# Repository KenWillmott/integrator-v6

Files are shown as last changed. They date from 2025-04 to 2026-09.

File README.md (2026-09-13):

# integrator-v6
guitar pickup test integrator V6.x

This hardware version of the integrator replaces the much older V5.8/V5.9 integrator.
General information about the integrator project is found here, along with the older design files:

https://github.com/KenWillmott/integrator/wiki

The newer V6.0 is a smaller, more integrated version of the same circuit, with upgraded components. It is possible to order a build from the factory. The BOM is a complete build, with all components, including switches and connectors. It is a fully functional integrator, needs only to be calibrated to work. A case or enclosure is recommended, So far an aluminum and an acrylic case have been used. It is possible to special order the boards without switches and connectors by noting them DNP on a modified BOM.

Complete BOM: [BOM-V601(2025-04-11).xls](https://github.com/KenWillmott/integrator-v6/blob/main/BOM-V601(2025-04-11).xls)

The project is listed at the PCBWay site, you can place an multi-board order there by following the ordering links and specifying "PCB+Assembly".
[PCBWay order link](https://www.pcbway.com/project/shareproject/W22492BSH46_integrator_V6_Gerber_e358a0f5.html)

Note that you can produce the PCB by any method, by importing the KiCad project and exporting the necessary fabrication files.

## Important!:
Some manufacturers and myself, have had problems sourcing the 3-way switch. So I provided onboard solder jumper J1 to select between 3-way (100-SP3) and 2-way
(100-SP1) switches. If the 100-SP3 is available, PCB V6.02 will work with no modifications and PCB 6.03 requires a solder blob on J1. If the 100-SP1 must be used, PCB V6.03 will work with no modifications and PCB V6.02 requires that C1 be either removed or not placed during production. Using the ON-ON functioning of the 100-SP1 will sacrifice the ability to make approximate inductance measurements, while preserving the no-load and loaded settings (which are the most important ones).

board-J1-settings

From a pure manufacturing point of view, the combinations

V6.02 --> 100SP3T1B4M7QE

V6.03 --> 100SP1T1B4M7QE

are preferred, since those configurations require no board or BOM modifications. However, V6.02 may be deprecated soon, since it's easier to modify V6.03 for either switch type.

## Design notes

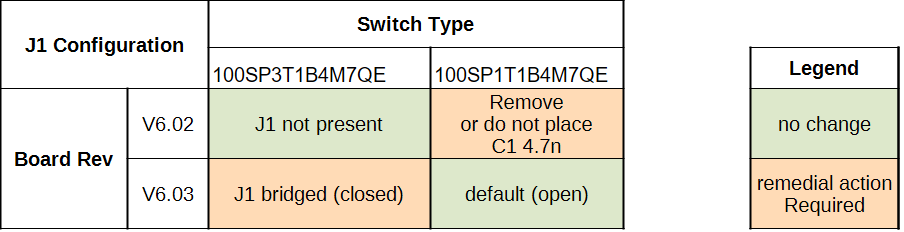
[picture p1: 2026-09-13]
board-J1-settings.png

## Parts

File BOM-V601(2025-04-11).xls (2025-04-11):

 |  |  | V6.02 Integrator BOM 2015-04-11
Item # | *Designator | *Qty | Manufacturer | *Mfg Part # | Description / Value | *Package/Footprint | Mounting Type
1 | R9,R6 | 2 | Yageo | RC0603JR-071M8L | 1.8M | R_0603_1608Metric | SMD
2 | C9,C12,C11 | 3 | Kemet | C0805C106K4PACTU | 10u 16V | C_0805_2012Metric | SMD
3 | R11,R12 | 2 | Yageo | RC0603FR-071KL | 1.0k | R_0603_1608Metric | SMD
4 | R5 | 1 | Yageo | RC0603JR-0718KL | 18k | R_0603_1608Metric | SMD
5 | J1 | 1 | TE Connectivity | 284391-3 | Screw_Terminal_01x03 | TerminalBlock_4Ucon_1x03_P3.50mm_Vertical | thru-hole
6 | R10,R7,R8 | 3 | Yageo | RC0603FR-1339KL | 39k | R_0603_1608Metric | SMD
7 | D1 | 1 |  | LTST-C191KRKT | LED | LED_0603_1608Metric | SMD
8 | U1 | 1 | Texas Instruments | TL084HIDR | Quad Op Amp | SOIC-14_3.9x8.7mm_P1.27mm | SMD
9 | J3 | 1 | CUI | SJ1-3525N | AudioJack2_Ground_Switch | Jack_3.5mm_CUI_SJ1-3525N_Horizontal | thru-hole
10 | C2 | 1 | Kemet | C0603X471K4RACAUTO | 470p | C_0603_1608Metric | SMD
11 | C7,C6 | 2 | Kemet | C0603C104K4RACTU | 100n | C_0603_1608Metric | SMD
12 | R4 | 1 | Yageo | RC0603FR-0710KL | 10k | R_0603_1608Metric | SMD
13 | D2 | 1 | EVVO | 1N4001W | 1N4001 | D_SOD-123 | SMD
14 | R1 | 1 | Yageo | RC0603FR-079M1L | 9.1M | R_0603_1608Metric | SMD
15 | C5 | 1 | EW Electronics | GKG30086 | 30p | C_Trimmer | SMD
16 | R2 | 1 | Yageo | RC0603JR-07200KL | 200k | R_0603_1608Metric | SMD
17 | C4 | 1 | Kemet | C0603C180J4GACTU | 18p | C_0603_1608Metric | SMD
18 | C8 | 1 | Kemet | C0603C105K4RACTU | 1.0u | C_0603_1608Metric | SMD
19 | SW1 | 1 | E-Switch | 100SP3T1B4M7QE | SW_SPDT_MSM | SPDT Toggle Switch | thru-hole
20 | R3 | 1 | Yageo | RC0603FR-071ML | 1.0M | R_0603_1608Metric | SMD
21 | U2 | 1 | ST Micro | L78L06ABUTR | L78L06_SOT89 | SOT-89-3 | SMD
22 | J2 | 1 | Tensility International | 54-00131 | Barrel_Jack_Switch | BarrelJack_GCT_DCJ200-10-A_Horizontal | thru-hole
23 | C3 | 1 | Kemet | C0603C399D4HACTU | 3.9p | C_0603_1608Metric | SMD
24 | C10 | 1 | Kemet | C0603C103M4RACTU | 10n | C_0603_1608Metric | SMD
25 | C1 | 1 | Kemet | C0603C472K4RACTU | 4.7n | C_0603_1608Metric | SMD

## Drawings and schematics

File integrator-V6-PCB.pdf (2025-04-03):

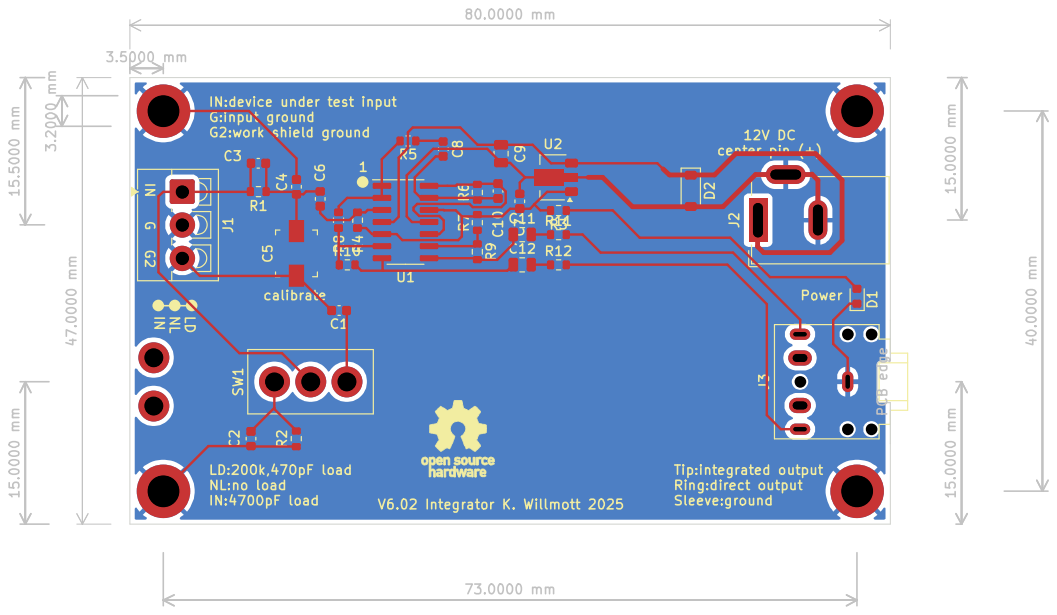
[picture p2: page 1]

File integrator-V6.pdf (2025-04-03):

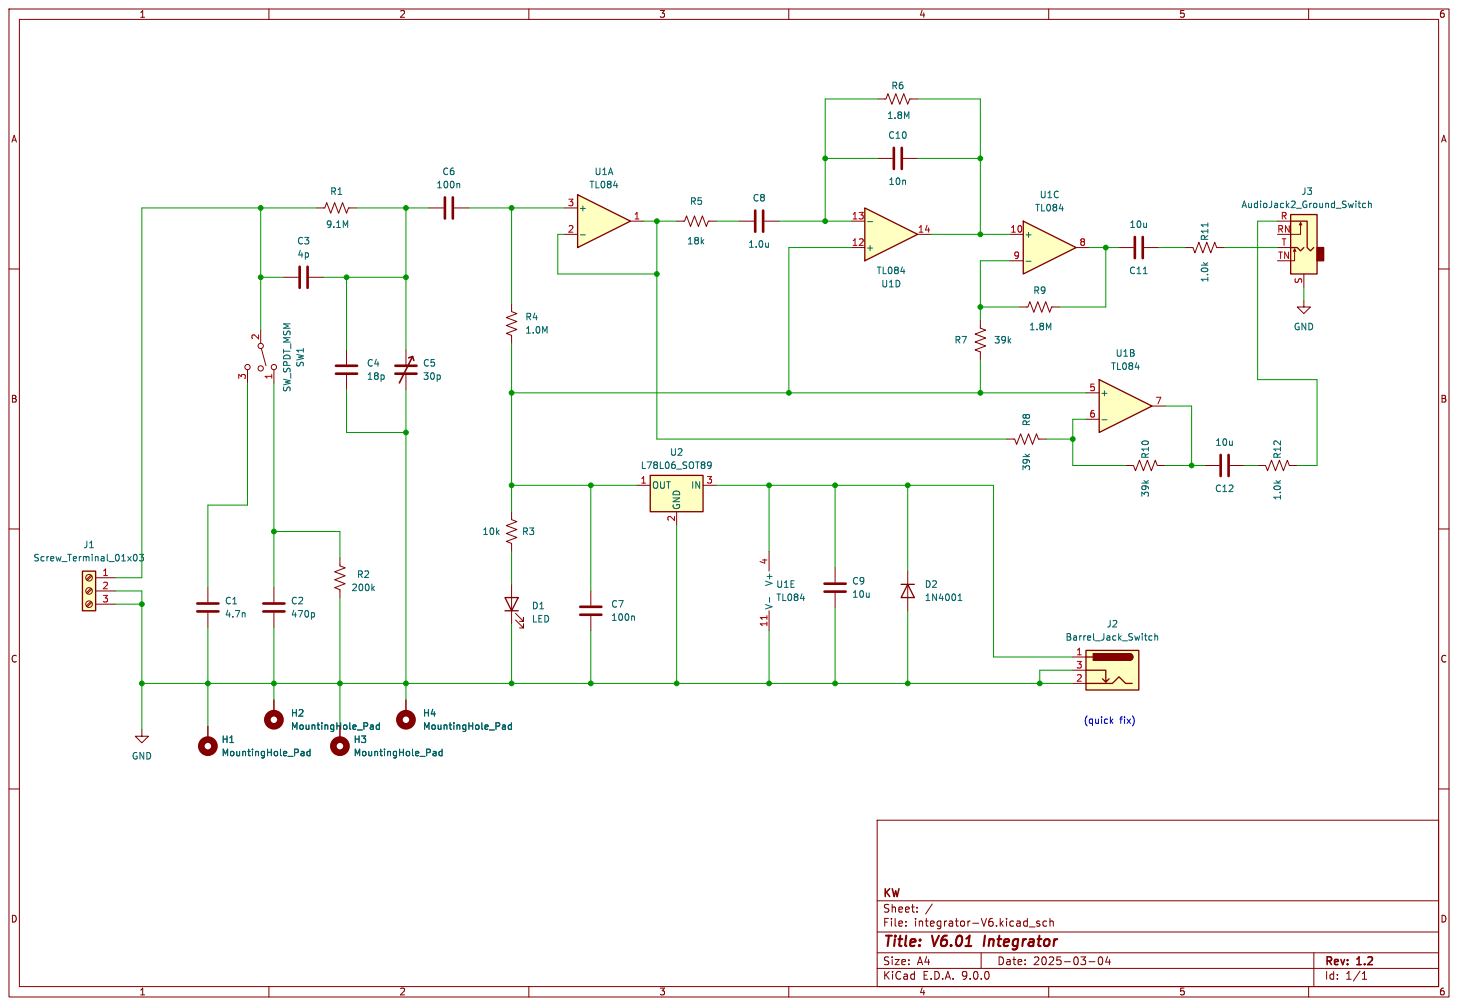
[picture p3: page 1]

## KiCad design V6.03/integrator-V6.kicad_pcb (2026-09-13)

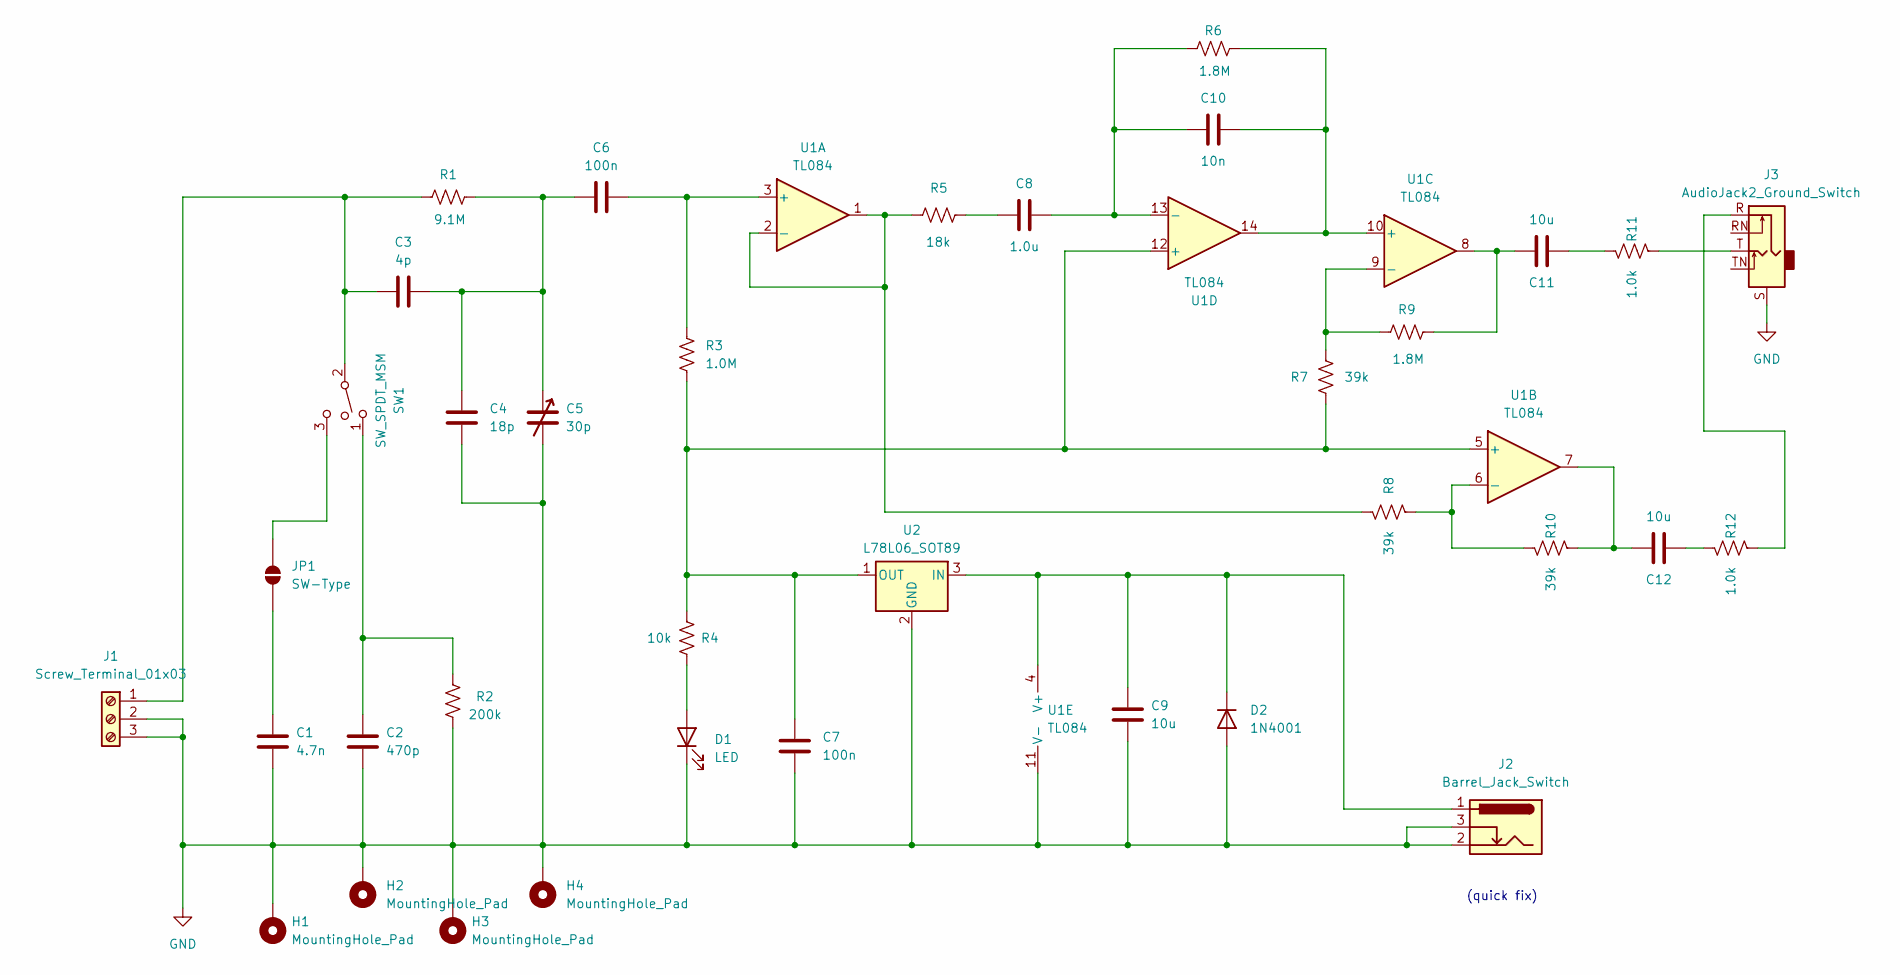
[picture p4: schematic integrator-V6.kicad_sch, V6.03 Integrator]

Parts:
C1: 4.7n; C_0603_1608Metric
C2: 470p; C_0603_1608Metric
C3: 4p; C_0603_1608Metric
C4: 18p; C_0603_1608Metric
C5: 30p; C_Trimmer_Murata_TZB4-A
C6, C7: 100n; C_0603_1608Metric
C8: 1.0u; C_0603_1608Metric
C9, C11, C12: 10u; C_0805_2012Metric
C10: 10n; C_0603_1608Metric
D1: LED; LED_0603_1608Metric
D2: 1N4001; D_SOD-123
H1, H2, H3, H4: MountingHole_Pad; MountingHole_3.2mm_M3_DIN965_Pad
J1: Screw_Terminal_01x03; TerminalBlock_4Ucon_1x03_P3.50mm_Vertical
J2: Barrel_Jack_Switch; BarrelJack_GCT_DCJ200-10-A_Horizontal
J3: AudioJack2_Ground_Switch; Jack_3.5mm_CUI_SJ1-3525N_Horizontal
JP1: SW-Type; SolderJumper-2_P1.3mm_Open_RoundedPad1.0x1.5mm
R1: 9.1M; R_0603_1608Metric
R2: 200k; R_0603_1608Metric
R3: 1.0M; R_0603_1608Metric
R4: 10k; R_0603_1608Metric
R5: 18k; R_0603_1608Metric
R6, R9: 1.8M; R_0603_1608Metric
R7, R8, R10: 39k; R_0603_1608Metric
R11, R12: 1.0k; R_0603_1608Metric
SW1: SW_SPDT_MSM; MTS-103 Switch
U1: TL084; SOIC-14_3.9x8.7mm_P1.27mm
U2: L78L06_SOT89; SOT-89-3

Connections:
GND: C1.2, C2.2, C4.1, C5.2, C7.2, C9.2, D1.1 (K), D2.2 (A), H1.1 (1_1), H2.1 (1_1), H3.1 (1_1), H4.1 (1_1), J1.2, J1.3, J2.2, J2.3, J3.S, R2.1, U1.11 (V-), U2.2 (GND)
unnamed: C2.1, R2.2, SW1.1
unnamed: C3.2, C4.2, C5.1, C6.2, R1.2
unnamed: C8.2, R5.1
unnamed: C11.1, R9.2, U1.8
unnamed: C11.2, R11.1
unnamed: C12.1, R10.2, U1.7
unnamed: C12.2, R12.1
unnamed: D1.2 (A), R4.2
unnamed: C9.1, D2.1 (K), J2.1, U1.4 (V+), U2.3 (IN)
unnamed: C3.1, J1.1, R1.1, SW1.2
unnamed: J3.R, R12.2
unnamed: J3.T, R11.2
unnamed: C1.1, JP1.1 (A)
unnamed: JP1.2 (B), SW1.3
unnamed: C6.1, R3.1, U1.3 (+)
unnamed: R5.2, R8.1, U1.1, U1.2 (-)
unnamed: C7.1, R3.2, R4.1, R7.2, U1.5 (+), U1.12 (+), U2.1 (OUT)
unnamed: R8.2, R10.1, U1.6 (-)
unnamed: C10.1, R6.2, U1.10 (+), U1.14
unnamed: R7.1, R9.1, U1.9 (-)
unnamed: C8.1, C10.2, R6.1, U1.13 (-)

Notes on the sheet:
(quick fix)

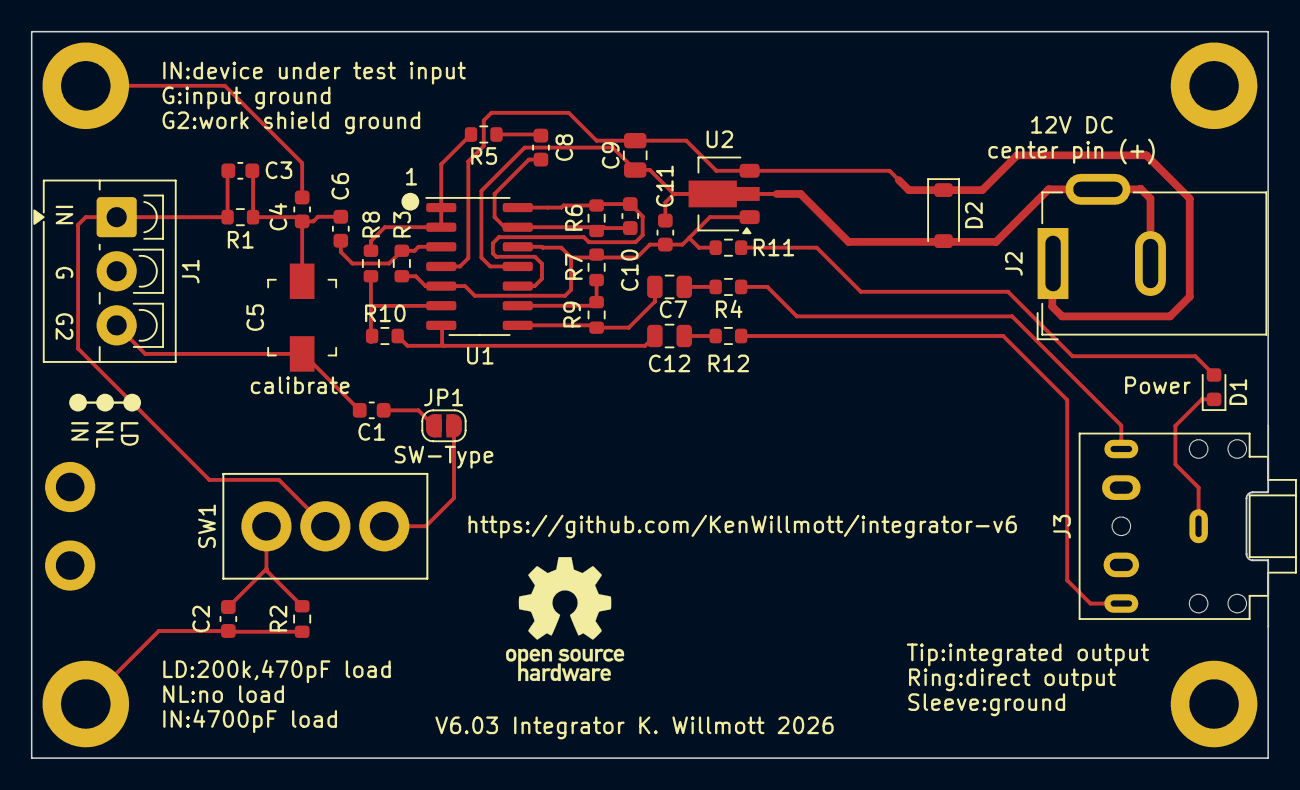
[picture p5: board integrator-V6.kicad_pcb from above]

Board: 2 copper layers, 80.0 x 47.0 mm, 37 parts (0 on the bottom side), 22 nets.

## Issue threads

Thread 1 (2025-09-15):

Sorry not an issue

SoLongSidekick, 2025-09-15:
I'm sorry for using this, Github really needs to add a "comments" section. But if you're open to help with this I'd love to help. I have FDM and resin 3D printers, 40w laser, 2 small CNC machines, uV printer, and have developed a CNC workflow to make PCBs that look like 95% the quality a fabhouse does; with solder mask and silkscreen plus gold pad coating. More importantly I lost all my musical gear so I'm starting over at a crappy Squire Strat body and probably homemade pickups with a few crazy electronic additions as my main playing guitar. I'm gonna be doing a ton of pickup testing and this is amazing.

If you don't want help I'll most likely be building it anyways, it's just too freaking cool. One of my first big hobby purchases when I got back on my feet recently was a digital oscilloscope, a Siglent SDS1104X-U. I know I can hook it up to my computer for some things, do you know exactly what capability is required regarding the 'scope? If the answer is "it has to be the Velleman unit" that's cool I'll figure out a way to get one, just don't want to spend cash if I already have a workable tool you know?

I've looooong wondered how in the hell a simple magnet with wire wrapped around it could really make that much of a difference to command the prices "quality" pickups do. I'm so confident that ~80% of electric guitar sound comes from the speaker in the amplifier and maybe 20% of it is the pickups - and that ~20% is mostly a "as long as it's not built with super cheap materials and you have the right amount of winding for the effect you're looking for you get full points" kind of thing and there really isn't the kind of variation to legitimize the insane number of offerings that pickup manufacturers are selling. I've realized that so, so much of what I used to "know" about the electric guitar was completely based on "common knowledge" and personal bias and I want to go through and freaking test what I should have tested 20 freaking years ago...

Ok novel over, regardless thanks for sharing the awesome project.

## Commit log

2025-04-03 Add files via upload
    schematic
2025-11-10 Update README with details about integrator V6
    Added detailed information about the V6 integrator, including links to documentation and BOM details.
2025-11-10 Add BOM file reference to README
2025-11-10 Update BOM link in README.md
2025-11-10 Update README with BOM link and enclosure recommendation
2025-11-10 Update README with BOM details and ordering options
    Removed mention of two BOMs and clarified ordering options.
2025-11-10 Update README with PCB ordering and production info
    Added information about ordering and producing PCBs.
2025-11-10 Update PCBWay order link in README
